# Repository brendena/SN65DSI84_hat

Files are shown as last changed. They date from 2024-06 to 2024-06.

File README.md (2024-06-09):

# SN64DSI84_hat
This is a dev board for the pi 5 to take the DSI input and output LVDS.  To do this, the board uses the [SN64DSI84](SN65DSI84).  This chip should be able to output most types of pinout.  It has a 30 pin flat connector and a 2.0mm pitch header poinout to do to most all pinouts.  There's external inputs for power for the LCD and LED if it has them.  

## important links
* [LVDS pinouts](https://hackaday.io/project/179868-all-about-laptop-display-reuse/log/193081-common-lvds-laptop-panel-pinouts)
* [eDP version of this board](https://github.com/brendena/SN65DSI86_hat)

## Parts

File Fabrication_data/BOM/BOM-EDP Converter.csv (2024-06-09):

Comment | Designator | Footprint | MPN
10uF | C1,C3,C15 | Capacitor_SMD:C_0603_1608Metric | GRM188R61A106ME69D
4.7uF | C2 | Capacitor_SMD:C_0603_1608Metric | CL10A475KO8NNNC
100nF | C4,C16,C30,C32,C34,C36,C39 | Capacitor_SMD:C_0402_1005Metric | CL05B104KP5NNNC
1uF | C14,C35,C38 | Capacitor_SMD:C_0402_1005Metric | CL05A105KO5NNNC
0.01uF | C17,C23,C29,C31 | Capacitor_SMD:C_0402_1005Metric | GRM155R71C103KA01D
SN65DSI84TPAPRQ1 | IC1 | QFP50P1200X1200X120-65N | SN65DSI84TPAPRQ1
Barrel_Jack | J1,J6 | Pattern:CUI_PJ-037AH | PJ-037AH
Conn_01x22_Socket | J2 | Connector_FFC-FPC:TE_2-1734839-2_1x22-1MP_P0.5mm_Horizontal | 2-1734839-2 / FH12-22S-0.5SH(55)
Conn_02x20_Odd_Even | J5 | Connector_PinHeader_2.00mm:PinHeader_2x20_P2.00mm_Vertical | 57102-G06-20LF
Conn_02x20_Odd_Even | J3 | Connector_PinSocket_2.54mm:PinSocket_2x20_P2.54mm_Vertical | SFH11-PBPC-D20-ST-BK
20455-030E-76 | J4 | Pattern:IPEX_20455-030E-76 | 20455-030E-76
2.2uH | L1 | Pattern:Induct | MHCI05018-2R2M-R8A
100k | R1 | Resistor_SMD:R_0402_1005Metric | RC0402FR-07100KL
4.7k | R2,R3 | Resistor_SMD:R_0402_1005Metric | RC0402JR-074K7L
0R | R4,R6,R7,R14,R15,R16,R17,R18,R19,R20,R21,R22,R23,R24,R25,R26,R27,R28 | Resistor_SMD:R_0402_1005Metric | RC1005J000CS
200k | R5 | Resistor_SMD:R_0402_1005Metric | RC0402FR-07200KL
1k | R8 | Resistor_SMD:R_0402_1005Metric | RC0402JR-071KL
0R-DNP | R9 | Resistor_SMD:R_0402_1005Metric | DNP
TLV62569DBVR | U1 | Pattern:SOT95P280X145-5N | TLV62569DBVR
TXB0104RGY | U4 | Package_DFN_QFN:Texas_S-PVQFN-N14 | TXB0104RGYR
74LVC1G07 | U5 | Package_TO_SOT_SMD:SOT-353_SC-70-5 | SN74LVC1G07DCKR
ASCO | X1 | Oscillator:Oscillator_SMD_Abracon_ASCO-4Pin_1.6x1.2mm | ASCO2-27.000MHZ-EK-T3

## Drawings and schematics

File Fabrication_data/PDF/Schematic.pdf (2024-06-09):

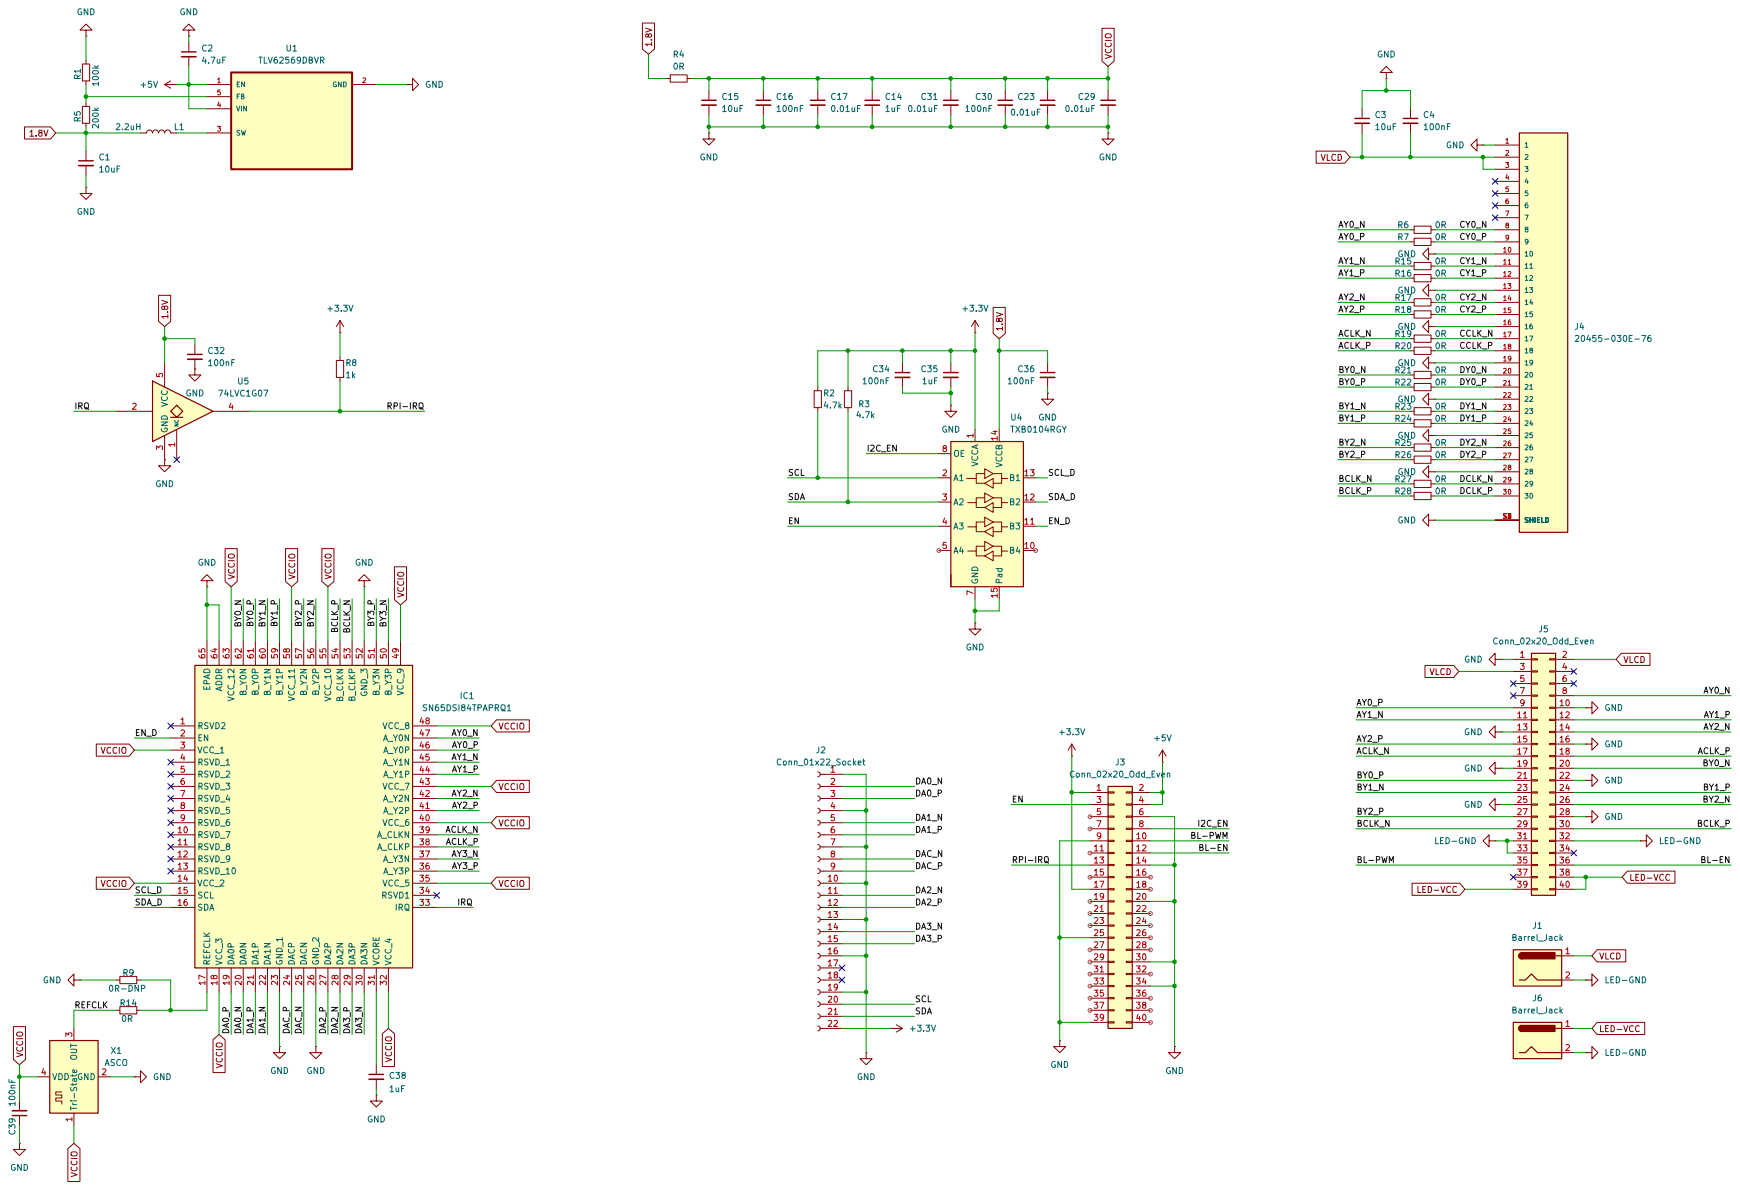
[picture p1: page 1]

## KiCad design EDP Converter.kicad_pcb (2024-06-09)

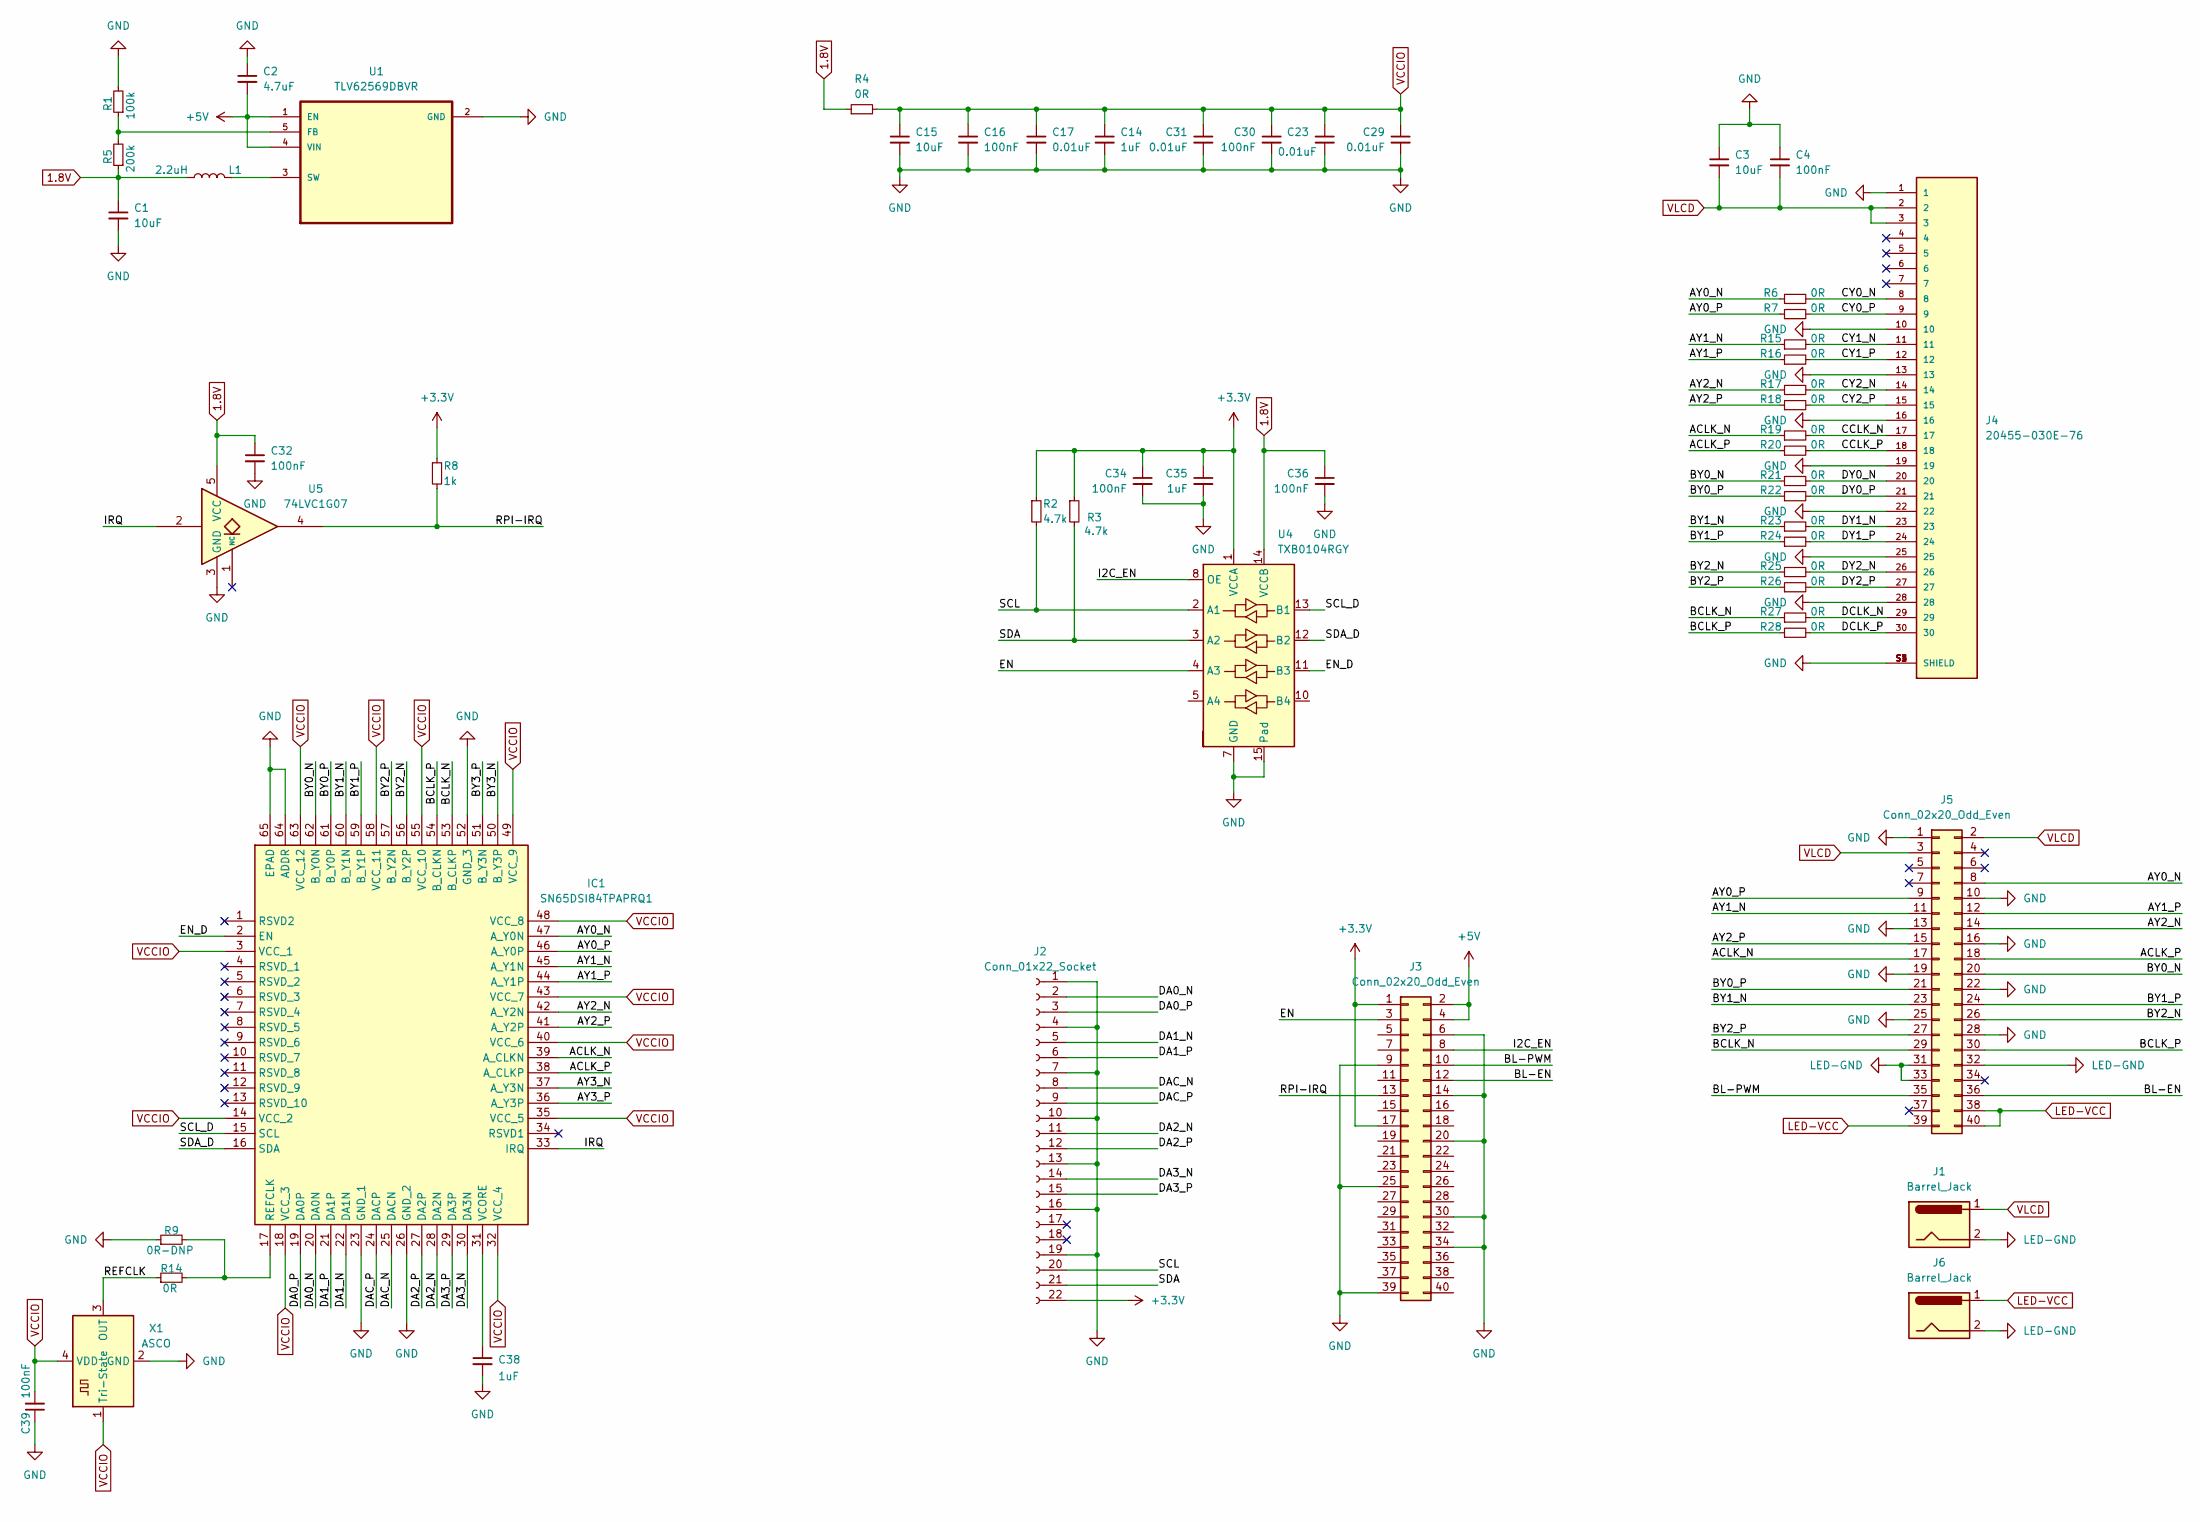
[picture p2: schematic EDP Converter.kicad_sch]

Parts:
C1, C3, C15: 10uF; C_0603_1608Metric; MPN GRM188R61A106ME69D
C2: 4.7uF; C_0603_1608Metric; MPN CL10A475KO8NNNC; LCSC C19666
C4, C16, C30, C32, C34, C36, C39: 100nF; C_0402_1005Metric; MPN CL05B104KP5NNNC
C14, C35, C38: 1uF; C_0402_1005Metric; MPN CL05A105KO5NNNC
C17, C23, C29, C31: 0.01uF; C_0402_1005Metric; MPN GRM155R71C103KA01D
IC1: SN65DSI84TPAPRQ1; QFP50P1200X1200X120-65N; Mouser Part Number 595-SN65DSI84TPAPRQ1
J1, J6: Barrel_Jack; CUI_PJ-037AH; MPN PJ-037AH
J2: Conn_01x22_Socket; TE_2-1734839-2_1x22-1MP_P0.5mm_Horizontal; MPN 2-1734839-2 / FH12-22S-0.5SH(55)
J3: Conn_02x20_Odd_Even; PinSocket_2x20_P2.54mm_Vertical; MPN SFH11-PBPC-D20-ST-BK
J4: 20455-030E-76; IPEX_20455-030E-76; MPN 20455-030E-76
J5: Conn_02x20_Odd_Even; PinHeader_2x20_P2.00mm_Vertical
L1: 2.2uH; Induct; MPN MHCI05018-2R2M-R8A; LCSC C329376
R1: 100k; R_0402_1005Metric; MPN RC0402FR-07100KL
R2, R3: 4.7k; R_0402_1005Metric; MPN RC0402JR-074K7L
R4, R6, R7, R14, R15, R16, R17, R18, R19, R20, R21, R22, R23, R24, R25, R26, R27, R28: 0R; R_0402_1005Metric; MPN RC1005J000CS
R5: 200k; R_0402_1005Metric; MPN RC0402FR-07200KL; LCSC C114763
R8: 1k; R_0402_1005Metric; MPN RC0402JR-071KL
R9: 0R-DNP; R_0402_1005Metric; MPN RC1005J000CS
U1: TLV62569DBVR; SOT95P280X145-5N; MPN TLV62569DBVR; LCSC C141836
U4: TXB0104RGY; Texas_S-PVQFN-N14; MPN TXB0104RGYR
U5: 74LVC1G07; SOT-353_SC-70-5; MPN SN74LVC1G07DCKR
X1: ASCO; Oscillator_SMD_Abracon_ASCO-4Pin_1.6x1.2mm; MPN ASCO2-27.000MHZ-EK-T3

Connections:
1.8V: C1.1, C32.1, C36.1, L1.1, R4.1, R5.1, U4.14 (VCCB), U5.5 (VCC)
+3.3V: C34.1, C35.1, J2.22, J3.1, J3.17, R2.1, R3.1, R8.1, U4.1 (VCCA)
+5V: C2.2, J3.2, J3.4, U1.1 (EN), U1.4 (VIN)
/ACLK_N: IC1.39 (A_CLKN), J5.17, R19.1
/ACLK_P: IC1.38 (A_CLKP), J5.18, R20.1
/AY0_N: IC1.47 (A_Y0N), J5.8, R6.1
/AY0_P: IC1.46 (A_Y0P), J5.9, R7.1
/AY1_N: IC1.45 (A_Y1N), J5.11, R15.1
/AY1_P: IC1.44 (A_Y1P), J5.12, R16.1
/AY2_N: IC1.42 (A_Y2N), J5.14, R17.1
/AY2_P: IC1.41 (A_Y2P), J5.15, R18.1
/AY3_N: IC1.37 (A_Y3N)
/AY3_P: IC1.36 (A_Y3P)
/BCLK_N: IC1.53 (B_CLKP), J5.29, R27.1
/BCLK_P: IC1.54 (B_CLKN), J5.30, R28.1
/BL-EN: J3.12, J5.36
/BL-PWM: J3.10, J5.35
/BY0_N: IC1.62 (B_Y0N), J5.20, R21.1
/BY0_P: IC1.61 (B_Y0P), J5.21, R22.1
/BY1_N: IC1.60 (B_Y1N), J5.23, R23.1
/BY1_P: IC1.59 (B_Y1P), J5.24, R24.1
/BY2_N: IC1.56 (B_Y2P), J5.26, R25.1
/BY2_P: IC1.57 (B_Y2N), J5.27, R26.1
/BY3_N: IC1.50 (B_Y3P)
/BY3_P: IC1.51 (B_Y3N)
/CCLK_N: J4.17, R19.2
/CCLK_P: J4.18, R20.2
/CY0_N: J4.8, R6.2
/CY0_P: J4.9, R7.2
/CY1_N: J4.11, R15.2
/CY1_P: J4.12, R16.2
/CY2_N: J4.14, R17.2
/CY2_P: J4.15, R18.2
/DA0_N: IC1.20 (DA0N), J2.2
/DA0_P: IC1.19 (DA0P), J2.3
/DA1_N: IC1.22 (DA1N), J2.5
/DA1_P: IC1.21 (DA1P), J2.6
/DA2_N: IC1.28 (DA2N), J2.11
/DA2_P: IC1.27 (DA2P), J2.12
/DA3_N: IC1.30 (DA3N), J2.14
/DA3_P: IC1.29 (DA3P), J2.15
/DAC_N: IC1.25 (DACN), J2.8
/DAC_P: IC1.24 (DACP), J2.9
/DCLK_N: J4.29, R27.2
/DCLK_P: J4.30, R28.2
/DY0_N: J4.20, R21.2
/DY0_P: J4.21, R22.2
/DY1_N: J4.23, R23.2
/DY1_P: J4.24, R24.2
/DY2_N: J4.26, R25.2
/DY2_P: J4.27, R26.2
/EN: J3.3, U4.4 (A3)
/EN_D: IC1.2 (EN), U4.11 (B3)
/I2C_EN: J3.8, U4.8 (OE)
/IRQ: IC1.33 (IRQ), U5.2
/REFCLK: R14.1, X1.3 (OUT)
/RPI-IRQ: J3.13, R8.2, U5.4
/SCL: J2.20, R2.2, U4.2 (A1)
/SCL_D: IC1.15 (SCL), U4.13 (B1)
/SDA: J2.21, R3.2, U4.3 (A2)
/SDA_D: IC1.16 (SDA), U4.12 (B2)
GND: C1.2, C2.1, C3.1, C4.1, C14.2, C15.2, C16.2, C17.2, C23.2, C29.2, C30.2, C31.2, C32.2, C34.2, C35.2, C36.2, C38.2, C39.1, IC1.23 (GND_1), IC1.26 (GND_2), IC1.52 (GND_3), IC1.64 (ADDR), IC1.65 (EPAD), J2.1, J2.4, J2.7, J2.10, J2.13, J2.16, J2.19, J3.6, J3.9, J3.14, J3.20, J3.25, J3.30, J3.34, J3.39, J4.1, J4.10, J4.13, J4.16, J4.19, J4.22, J4.25, J4.28, J4.S1 (SHIELD), J4.S2 (SHIELD), J4.S3 (SHIELD), J4.S4 (SHIELD), J5.1, J5.10, J5.13, J5.16, J5.19, J5.22, J5.25, J5.28, R1.2, R9.1, U1.2 (GND), U4.7 (GND), U4.15 (Pad), U5.3 (GND), X1.2 (GND)
LED-GND: J1.2, J5.31, J5.32, J5.33, J6.2
LED-VCC: J5.38, J5.39, J5.40, J6.1
unnamed: IC1.17 (REFCLK), R9.2, R14.2
unnamed: C38.1, IC1.31 (VCORE)
unnamed: R1.1, R5.2, U1.5 (FB)
unnamed: L1.2, U1.3 (SW)
VCCIO: C14.1, C15.1, C16.1, C17.1, C23.1, C29.1, C30.1, C31.1, C39.2, IC1.3 (VCC_1), IC1.14 (VCC_2), IC1.18 (VCC_3), IC1.32 (VCC_4), IC1.35 (VCC_5), IC1.40 (VCC_6), IC1.43 (VCC_7), IC1.48 (VCC_8), IC1.49 (VCC_9), IC1.55 (VCC_10), IC1.58 (VCC_11), IC1.63 (VCC_12), R4.2, X1.1 (Tri-State), X1.4 (VDD)
VLCD: C3.2, C4.2, J1.1, J4.2, J4.3, J5.2, J5.3

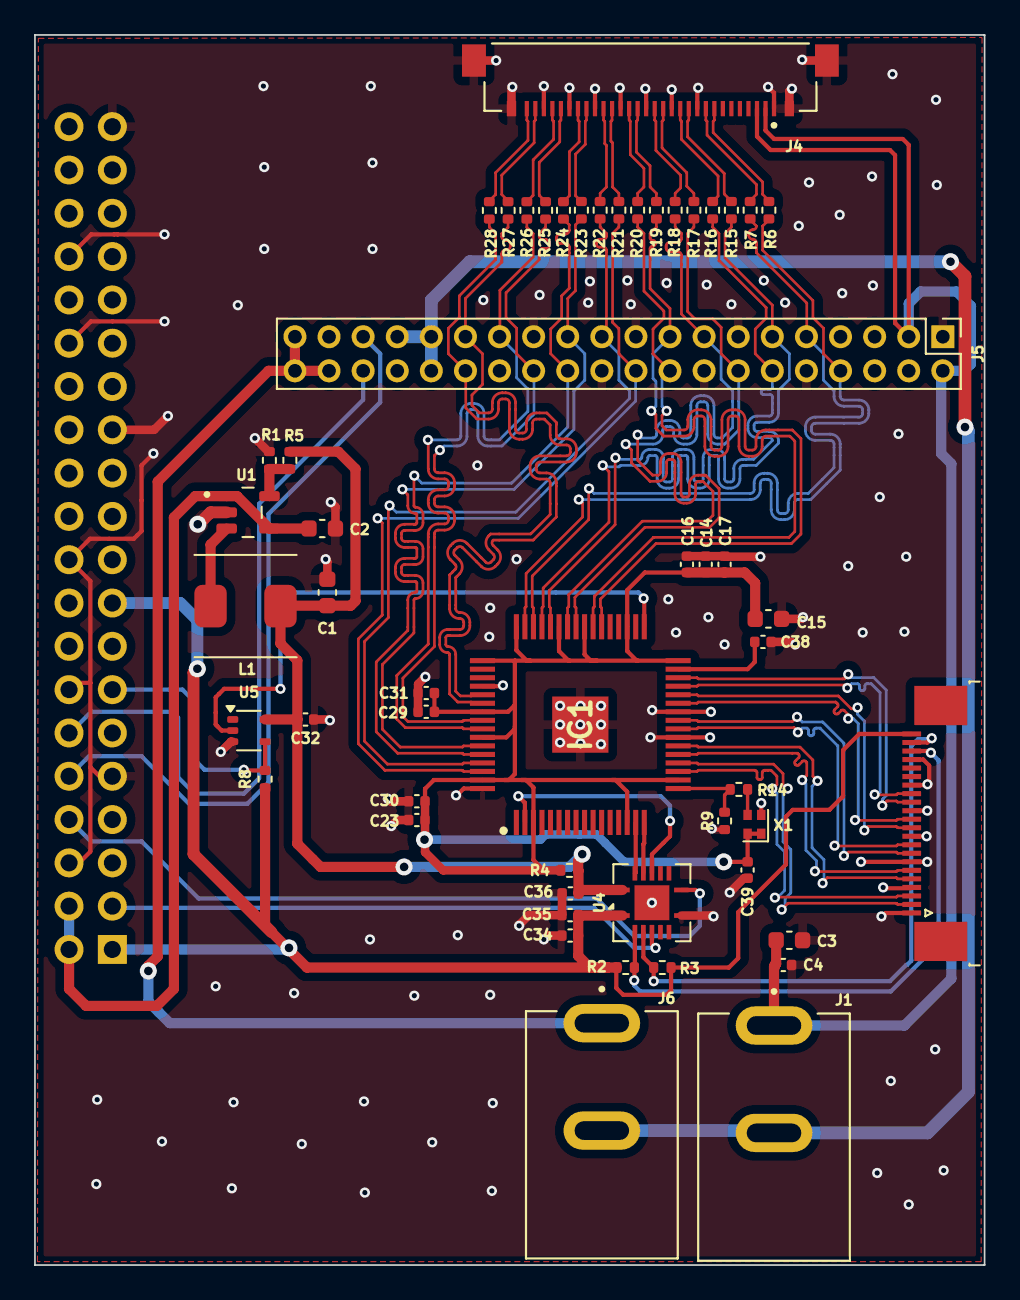
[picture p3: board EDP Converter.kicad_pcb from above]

Board: 4 copper layers, 55.7 x 72.2 mm, 54 parts (1 on the bottom side), 66 nets.

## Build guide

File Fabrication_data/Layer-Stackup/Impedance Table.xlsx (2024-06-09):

Layer | Trackwidth/Space(mm) | Single/Differential | Impedance(Ohm) | Reference layer
F-Cu | 0.16/0.2 | Differential | 100 | IN1-Cu
IN1-Cu | Reference Power Plans
IN2-Cu
B-Cu | 0.16/0.2 | Differential | 100 | IN2-Cu
